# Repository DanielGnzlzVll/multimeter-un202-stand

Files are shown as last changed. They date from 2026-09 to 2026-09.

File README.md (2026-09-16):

# Unity UN202 multimeter stand

A compact folding kickstand for the Unity UN202 clamp multimeter, using
the existing top case screw (the one just below the jaw) as the mount
point. Three printed parts (pick one of the two base options) plus,
for the screw-based base, one M3 screw and nut:

- **`base_tab()`** — a small tab with a plain, fully-enclosed hole for
  a *replacement* screw (head ~5mm, shank ~3mm — swap in for the
  original case screw). The original screw comes out completely, is
  passed through this hole from behind, and driven back into the
  case, so its head clamps the tab flush. Because it's a plain hole
  (not a slot), the tab can only come off by being fully unscrewed
  again.
- **`base_plug()`** — a hardware-free alternative: a peg that presses
  tightly into the screw's recess (~5.6mm) instead of using the screw
  at all. Split into flexible fingers (a simple collet) so it
  self-adjusts across a range of real hole sizes instead of relying on
  one exact diameter. Simpler assembly, but it means pulling the screw
  out permanently and relying on the peg's grip alone.
- **`leg()`** — attaches to whichever base through a printed knuckle
  hinge, pinned with an M3 screw and nut. This is the part that
  actually folds flat against the meter when stowed and swings out to
  prop it up when deployed. **The M3 nut is the friction adjustment**
  — tighter clamps the knuckles together harder, holding the leg at
  whatever angle you leave it, including flush against the case.

Render/print with:

```
openscad --render -o stand.stl stand.scad
```

## File formats

- `stand.stl` — all three parts, laid out for printing (this is what
  you actually print).
- `stand.step` — the same layout, converted to STEP for tools that
  need it.
- `step/base_tab.step`, `step/base_plug.step`, `step/leg.step` — each
  part individually, for importing into a CAD assembly.

**Important caveat on the STEP files:** OpenSCAD has no true CAD
kernel — every curved surface (every cylinder, every hole) is always a
faceted polygon approximation (controlled by `$fn`), never a smooth
analytic surface. The STEP files here are that same faceted mesh
wrapped in STEP's container format (converted from the STL with
OpenCASCADE), not a real parametric/smooth-surface model. They're
useful for tools that only accept STEP, or for importing into a CAD
assembly, but don't expect smooth cylinders if you inspect the
surfaces closely, and don't expect to edit dimensions non-destructively
the way you could with a native CAD part — `stand.scad` is still the
actual source of truth for any dimensional changes.

## Renders

All three parts, laid out as they print:

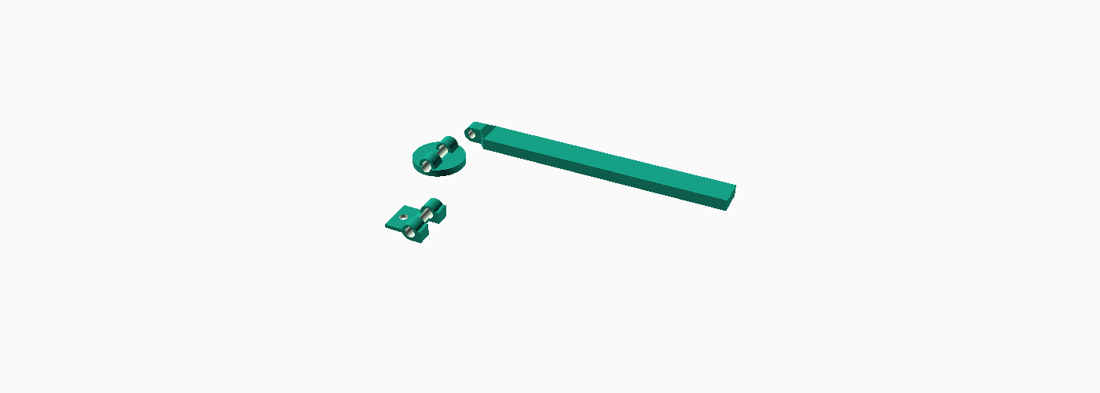
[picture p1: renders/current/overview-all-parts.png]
All parts


`base_tab` — thin insertion tab tapering into a thick hinge anchor:

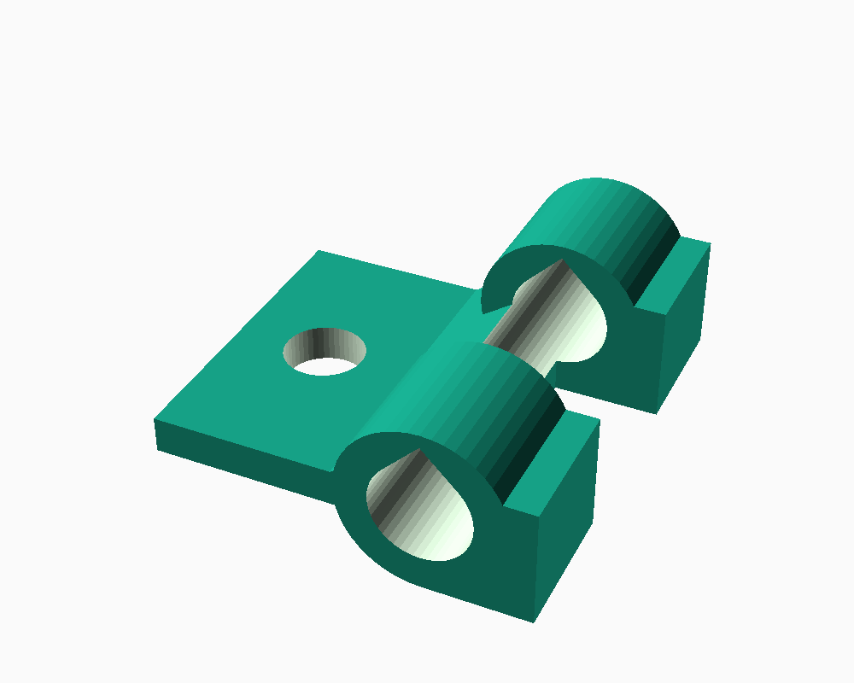
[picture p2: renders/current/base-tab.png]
base_tab


`base_plug` — press-fit peg, flange, and the same thick hinge anchor:

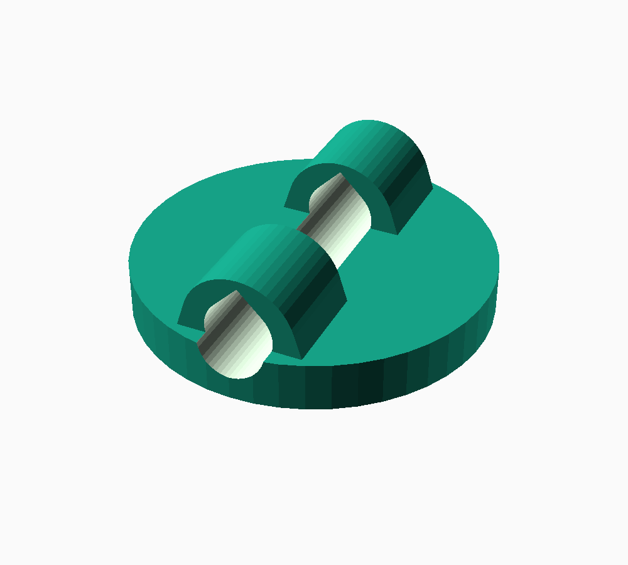
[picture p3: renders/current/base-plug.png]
base_plug


`leg` — hinge knuckle, tapered strip, foot pad:

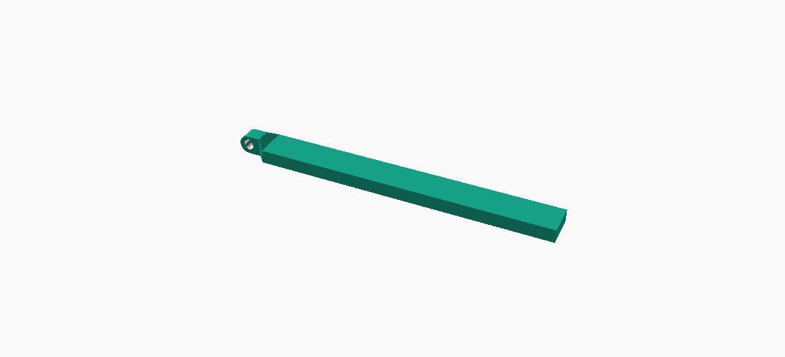
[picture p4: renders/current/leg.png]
leg


All parts are laid out flat side-by-side at the bottom of the file,
ready to print with no supports. Every M3 hinge bore uses a teardrop
profile (circle + a 45° point on top) instead of a plain round hole,
so it prints cleanly with no bridging/support even lying flat with the
bore axis horizontal. Each bore's cutter also extends well past the
finger/knuckle's own edges (not just ~1mm) — a smaller margin reliably
left a hair-thin sliver of uncut material right at the opening, close
enough to being a real M3 screw obstruction to fix outright. Verified
by literally modeling an M3 screw shaft and checking for zero overlap
with each part.

## Why two hinges' worth of thinking, but only one moving joint

The case screw's axis points straight into the case, so anything
pivoting directly on it can only sweep flat across the back (like a
clock hand) — it can't lift away from the surface to prop the meter
up. So the *base* (tab or plug) just anchors a fixed attachment point,
and a **separate** knuckle hinge (axis parallel to the case surface,
pinned by the M3 hardware) is what actually lets the leg fold out.
That second hinge is the only moving joint.

## Leg length math

With the meter resting on its bottom edge and tilted back to
`tilt_angle`, the top screw sits at height `screw_height_from_bottom *
sin(tilt_angle)` above the table. Swinging the leg out from
flush-against-the-case by `deploy_hinge_angle` needs a leg length of:

```
leg_length_raw = screw_height_from_bottom * sin(tilt_angle) / sin(tilt_angle - deploy_hinge_angle)
leg_length = leg_length_raw - leg_shorten
```

(`deploy_hinge_angle` must stay less than `tilt_angle`, or the leg
never reaches the table no matter how long it is.) All three inputs
are adjustable at the top of `stand.scad`. `leg_shorten` (25mm default)
trims the geometric result directly — in practice it came out longer
than the meter itself, and shortening it was simpler and more honest
than fudging `screw_height_from_bottom` (a measurement) or the angles
(deliberate choices) just to change the length.

## Before printing: verify these assumptions

- `screw_height_from_bottom` (115mm default): distance from the
  meter's bottom edge, along the back, up to the top screw. Estimated
  from product photos, not measured on your actual unit — **measure
  this**, it directly drives the leg length.
- `shank_d` (2.6mm default): diameter of the screw shank under the
  head. Only the head (5.1mm) and the recess it sits in (~5.6mm) were
  actually measured.
- `new_screw_head_d` (5mm) / `new_screw_shank_d` (3mm): the
  replacement screw's dimensions — both estimates, measure the actual
  screw you're using. `base_t` (1.6mm) no longer has to stay thinner
  than a loosened-screw gap now that the screw is fully removed for
  installation, but there's no reason to change it either. Past the
  screw hole, `base_tab` tapers up to a much thicker, wider anchor
  block (`base_thick_t` 5mm, `base_thick_w` 14mm) for the hinge
  fingers, the same reasoning as `base_plug`'s peg-to-flange taper.
- `base_w` (14mm default, up from 9mm): width of the zone the screw
  head clamps down on. Widened to match `base_thick_w` so the screw
  presses the tab against the case over a much bigger flat area
  instead of a strip barely wider than the head itself.
- `peg_len` (5.5mm default) and `peg_interference` (0.4mm default): how
  deep the screw's recess actually is, and how much oversized to print
  the peg for a tight press fit. `peg_len` is kept 0.5mm short of the
  full estimated recess depth so the peg doesn't bottom out/crash into
  whatever is at the base of that hole before the flange seats flush.
  Both are guesses — start with a test print of just `base_plug()`
  before committing to a full print. (Only matters for `base_plug`.)
- `base_plug`'s peg is split into `peg_slot_count` (3) flexible
  fingers by `peg_slots()` — a simple collet, so it self-adjusts to a
  slightly bigger or smaller real hole (compressing or springing out)
  instead of being one rigid diameter that's either loose or won't go
  in. `peg_solid_top` (1mm) keeps a solid, unsplit hub at the flange
  end for the fingers to cantilever from.
- `base_plug`'s flange (22mm diameter, 3mm thick) and gusseted fingers
  are sized to comfortably out-span the hinge fingers and give the
  leg's leverage a wide shoulder to load into — deliberately sturdier
  than the bare minimum, since this piece takes all the load with no
  screw backing it up.
- The hinge knuckle itself (`finger_w`, 6mm) is wider than the original
  design (4mm) since the leg's knuckle — the part actually cantilevering
  the leg's whole load — is only `finger_w - 0.4` wide, and 3.6mm was
  thin enough to be a real breakage risk.
- `base_tab` and `base_plug`'s two hinge fingers stay free-standing at
  the top -- deliberately. The gap above and between them is exactly
  where the leg's own strip has to sweep through as it pivots, so any
  fixed material bridging their tops (tried once, reverted) blocks the
  hinge from moving at all, even though it looks like harmless
  reinforcement in a static render.
- `base_tab`'s original taper only built up material on the near side
  (toward the tab) of each finger, leaving the far side of each
  cylinder completely unsupported. Fixed with a matching cap on that
  far side -- flat, at the same low Z as the rest of the anchor block
  (not stacked upward), and confined to each finger's own Y-width so
  it can't reach into the gap between them. Verified this doesn't
  introduce any new collision with the leg at any rotation angle
  (checked 0-180° in 15-30° steps): identical residual overlap with or
  without the cap, meaning what's left is a small pre-existing
  tolerance artifact from the tight ~0.2mm knuckle-to-gap clearance,
  not something this fix caused.
- `deploy_hinge_angle` (15° default): arbitrary choice balancing leg
  length against how far the leg has to swing out. Adjust and
  re-derive `leg_length` (automatic) if you want a shorter/longer leg.
- `base_gap_pad` (1.5mm) and `base_m3_hole_d` (4.2mm, up from the
  shared `m3_hole_d` 3.6mm): after printing the leg, its actual
  knuckle didn't leave a clear path for the M3 screw through both
  bases' finger holes — printed solid features commonly come out
  slightly oversized and holes slightly undersized, and a tight
  nominal fit and a tight nominal bore stack up fast. These two widen
  the bases' own finger gap and hinge bore only — `leg()`'s own
  dimensions (and the already-printed part) are completely untouched.
- `leg`'s foot pad matches the strip's own width/thickness (`foot_w` =
  `leg_w`, `foot_t` = `leg_t`) instead of being wider and thinner, so
  the whole leg is one constant rectangular cross-section end to end —
  it can be rotated 90° in the slicer (printed standing on edge for a
  different layer orientation) without a flared foot sticking out past
  the rotated profile.

## Assembly

**With `base_tab` (replacement screw):**
1. Remove the original case screw entirely.
2. Pass the replacement screw through `base_tab`'s hole from behind,
   then drive it into the case's original threaded hole. The bigger
   head clamps the tab flush against the case.

**With `base_plug` (no hardware, screw comes out):**
1. Remove the top case screw entirely.
2. Press `base_plug`'s peg firmly into the empty recess until the
   flange seats against the case. The split fingers should self-adjust
   to your actual hole size; sand the peg down a bit if it's still too
   tight to seat fully.

**Both:**
3. Sandwich `leg`'s knuckle between the base's two knuckles, push the
   M3 screw through, add the nut.
4. Tighten the nut until the leg holds its position under the meter's
   weight but you can still reposition it by hand.

## History

`renders/v1-rigid-prototype/` has renders of the very first design
iteration (a rigid, fixed-angle prop) that was replaced by the current
folding-hinge approach — kept for reference only.

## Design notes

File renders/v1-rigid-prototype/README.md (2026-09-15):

# v1 prototype (superseded)

Renders of the very first design iteration (git commit `e32ad1b`): a
single rigid piece that clipped onto the screw head via a keyhole slot
and held the meter at a fixed 60° angle via its own separate foot on
the table.

This was replaced by the current two-part folding hinge design because
it didn't match the actual goal: it stuck out further than wanted and
couldn't adjust its angle. Kept here for reference only — see the
top-level README for the current design.

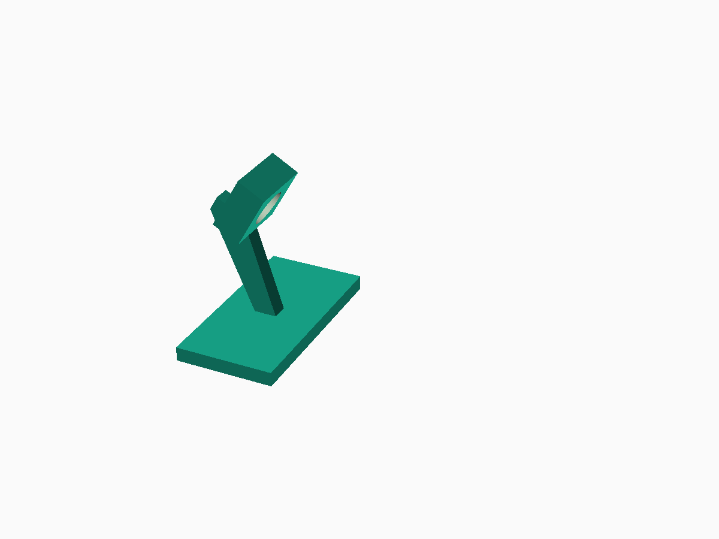
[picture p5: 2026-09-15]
renders/v1-rigid-prototype/overview.png

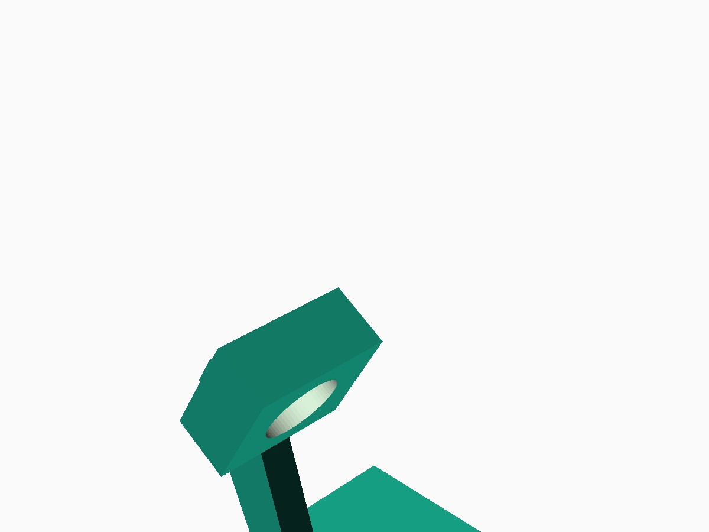
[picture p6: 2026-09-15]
renders/v1-rigid-prototype/clip-closeup.png

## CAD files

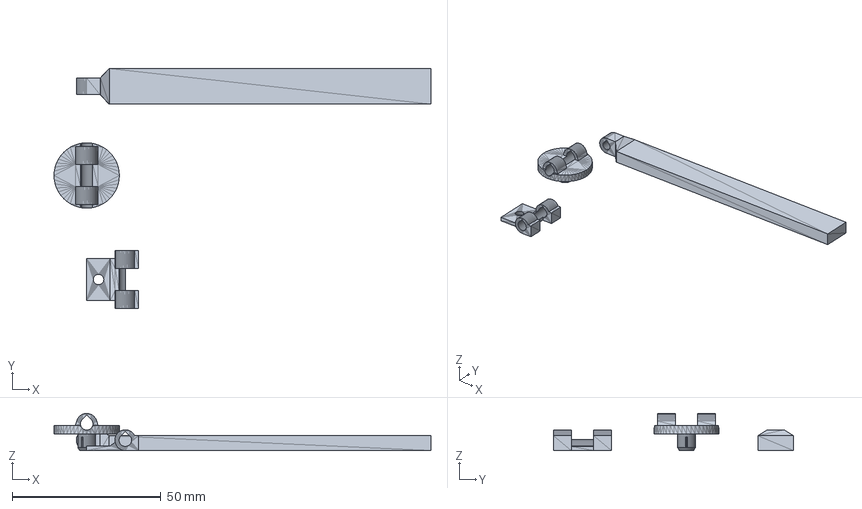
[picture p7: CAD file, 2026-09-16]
stand.step
126.8 x 80.8 x 12.5 mm

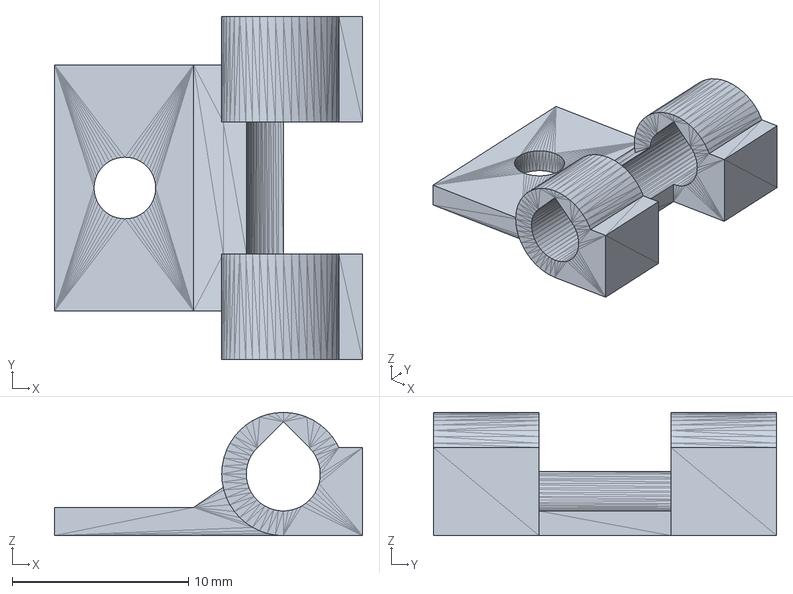
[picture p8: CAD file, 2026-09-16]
step/base_tab.step
17.5 x 19.5 x 7.00 mm

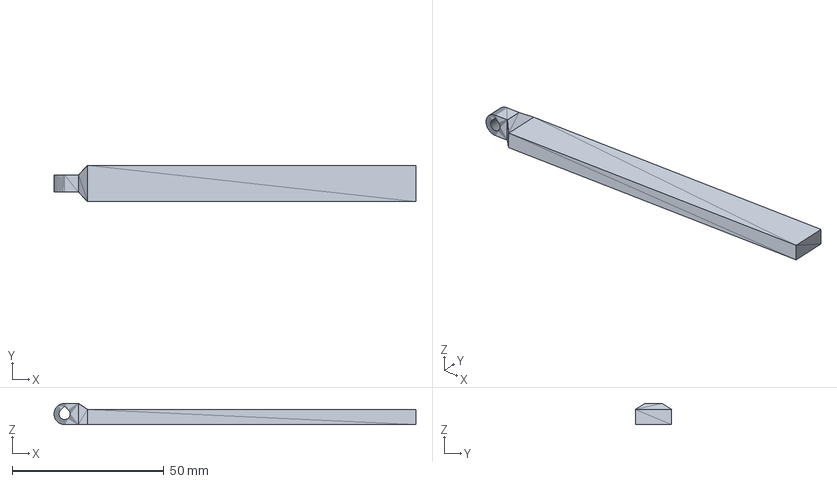
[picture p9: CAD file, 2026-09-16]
step/leg.step
119.3 x 12.0 x 7.00 mm

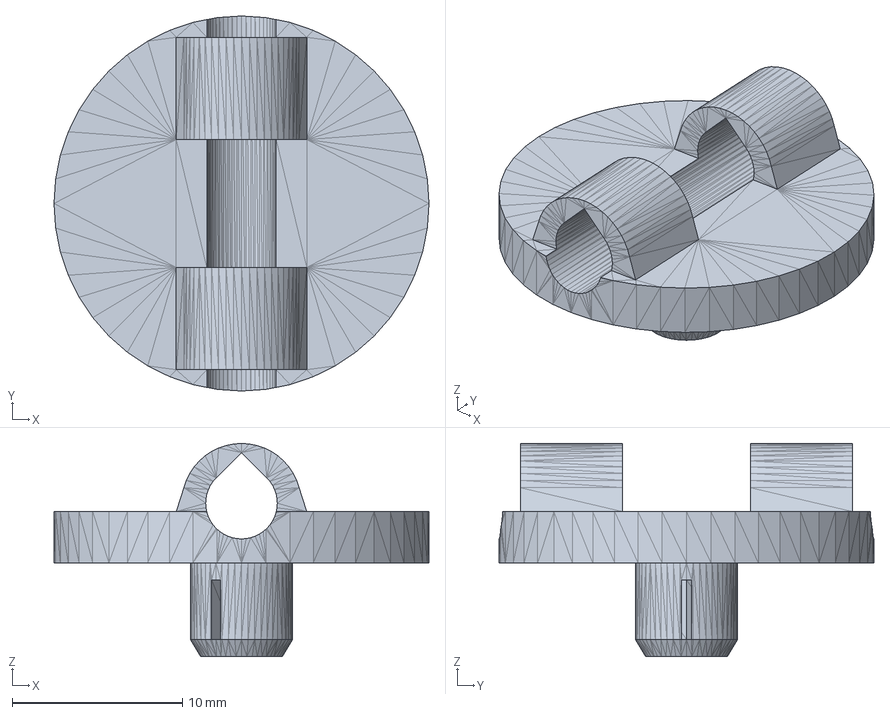
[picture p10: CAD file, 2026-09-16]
step/base_plug.step
22.0 x 22.0 x 12.5 mm

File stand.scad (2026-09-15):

// ============================================================
// Folding kickstand for Unity UN202 clamp multimeter
//
// One leg + a choice of two base attachments, plus one M3 screw
// and nut for the hinge:
//   1) base_tab()   - slides sideways under the loosened top case
//                     screw, sits flush against the case.
//   2) base_plug()  - alternative, no-hardware attachment: a peg
//                     that presses tightly into the screw's
//                     recess (no screw needed at all).
//   3) leg()        - attaches to whichever base through an M3
//                     bolt hinge (screw + nut = friction pivot).
//                     Folds flat against the case when stowed,
//                     swings out to prop the meter up when
//                     deployed. Tightening the nut sets how much
//                     friction holds whatever angle you leave it.
//
// MOST NUMBERS BELOW ARE ESTIMATES from product photos, not the
// real part. Print, test-fit, and correct the "ADJUST" sections.
// ============================================================

$fn = 48;

// ---------------- ADJUST: real screw/case measurements ----------
screw_head_d     = 5.1;   // measured
shank_d          = 2.6;   // ESTIMATE -- verify against the real screw shank
shank_clearance  = 0.5;
shank_hole_d     = shank_d + shank_clearance;
recess_d         = 5.6;   // measured diameter of the screw's recess/counterbore

// Distance from the meter's bottom edge, along the back, up to the
// TOP screw (below the jaw). Estimated from product photos --
// MEASURE THIS on the real meter, it directly sets the leg length.
screw_height_from_bottom = 115;

// ---------------- ADJUST: desired prop geometry ------------------
tilt_angle         = 60;  // meter's back angle from flat when propped up
deploy_hinge_angle = 15;  // how far the leg swings out (from lying flush
                           // against the case) to reach the table at
                           // tilt_angle. Must stay less than tilt_angle;
                           // smaller = longer leg but hugs the case
                           // closer while folding out.

// Required leg length so swinging the leg out by deploy_hinge_angle
// (from flush-against-the-case) lands the foot on the table with the
// meter resting on its bottom edge at tilt_angle. See README for the
// derivation.
leg_length_raw = screw_height_from_bottom * sin(tilt_angle) / sin(tilt_angle - deploy_hinge_angle);
// The geometric derivation above came out longer than the meter itself
// in practice. Trimmed directly rather than distorting the measured/
// chosen inputs above (which are either a real measurement or a
// deliberate angle choice, not free knobs to fudge for length alone).
leg_shorten = 25;
leg_length = leg_length_raw - leg_shorten;

// ---------------- Base tab (through-hole for a replacement screw) ---
// The original case screw is being swapped for a different one (head
// ~5mm, shank ~3mm) that's removed entirely, passed through a plain
// hole in the tab, and driven back into the case -- so the head
// clamps the tab flush against the case. This replaced an earlier
// loosen-and-slide keyhole design sized for the original screw; a
// plain hole is simpler now that the screw comes all the way out, and
// -- as a bonus -- means the tab can't come loose on its own at all,
// since it can only be removed by fully unscrewing it again.
new_screw_head_d       = 5;    // ADJUST -- replacement screw's head
new_screw_shank_d      = 3;    // ADJUST -- replacement screw's shank
new_screw_shank_clear  = 0.5;
new_screw_hole_d       = new_screw_shank_d + new_screw_shank_clear;

base_t = 1.6;  // thickness at the screw hole -- doesn't need to be
               // this thin anymore now that the screw is fully
               // removed for installation, but no reason to change it
base_l = 13;   // length, insertion edge to hinge knuckles
base_w = 14;   // width of the zone the screw head clamps down on --
               // widened from 9mm so it presses on a much bigger flat
               // area, instead of a narrow strip barely wider than
               // the head

// Past the screw hole, the tab doesn't need to stay thin -- nothing
// there has to slide under the screw head -- so it tapers up to a
// much thicker, wider anchor block for the hinge fingers to embed
// into, the same way base_plug()'s peg tapers into its flange.
base_thick_t = 5;   // thickness at the hinge end
base_thick_w = 14;  // width at the hinge end -- out-spans the fingers
                     // (hinge_span = 18mm) with real margin, instead of
                     // the original 9mm tab the fingers overhung badly

// ---------------- Press-fit base plug (no hardware) ---------------
// The peg alone (a rigid cylinder) was too loose -- printed hole sizes
// vary enough in practice that a single fixed diameter can't reliably
// grip. peg_interference is bumped up, and the peg itself is split
// into flexible fingers (see peg_slot_count etc. below) that compress
// or spring out to self-adjust across a range of real hole sizes,
// instead of relying on hitting one exact diameter.
peg_interference = 0.4;   // print the peg this much OVER recess_d;
                           // the split fingers below let it compress
                           // if that's too tight for your actual hole
peg_d    = recess_d + peg_interference;
peg_slot_count = 3;    // number of flexible fingers the peg is split
                        // into -- each can flex independently, so the
                        // peg self-adjusts to a slightly bigger or
                        // smaller real hole instead of being a single
                        // rigid diameter that's either loose or won't
                        // go in at all
peg_slot_w     = 0.6;  // slot width -- thin but printable at $fn=48
peg_solid_top  = 1;    // solid, unsplit hub left at the peg's own top
                        // (flange end) so the fingers have something
                        // rigid to cantilever from
peg_len  = 5.5;  // ADJUST -- how deep the recess actually is. Kept
                  // 0.5mm short of the full estimated recess depth so
                  // the peg doesn't bottom out/crash into whatever is
                  // at the base of that hole (e.g. the screw boss it
                  // used to thread into) before the flange seats flush.
                  // Shorten further if the real recess is shallower.
flange_d = 22;    // rests on the flat case surface around the recess.
                  // Sized to comfortably out-span the hinge fingers
                  // (hinge_span = 2*finger_w + knuckle_gap = 18mm) with
                  // real margin, so the leg's leverage has a wide
                  // shoulder to load into instead of overhanging it.
flange_t = 3;     // shoulder thickness -- doubled from 1.5mm so the
                  // flange resists the leg's leverage without flexing
                  // or cracking under load
lead_in  = 1;     // small chamfer at the peg's tip so it starts straight

// Gusset width: each hinge finger meets the flange through a hull()'d
// fillet instead of a bare, sharply-cornered tangent (same hull-taper
// trick leg() uses to blend its knuckle into the strip). Deliberately
// bigger than knuckle_od (7mm) -- anything narrower ends up entirely
// swallowed by the finger's own cylinder (hull of a shape inside
// another is a no-op), so it has to actually stick out past the
// finger to add material. The gusset's height is computed inside
// base_plug() itself, capped to stay clear of the hinge hole.
gusset_w = 9;   // x-extent of the gusset's flange-side footprint

// ---------------- Hinge (M3 screw + nut = friction pivot) --------
m3_hole_d     = 3.6;  // bumped from 3.4 -- FDM horizontal holes commonly print
                       // a bit undersized, and 3.4 was too tight for a clean M3 fit
knuckle_od    = 7;
knuckle_r     = knuckle_od / 2;
finger_w      = 6;                 // width of each base knuckle finger --
                                    // widened from 4mm since the leg's
                                    // knuckle (finger_w - 0.4) is the
                                    // thin part actually cantilevering
                                    // the whole leg's load
knuckle_gap   = finger_w;          // gap between the two base fingers
leg_knuckle_w = finger_w - 0.4;    // leg's single knuckle, fits the gap
hinge_span    = 2 * finger_w + knuckle_gap;
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

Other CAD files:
stand.stl

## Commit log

2026-09-15 Add parametric OpenSCAD kickstand for Unity UN202 multimeter
    Clips onto the existing case screw via a keyhole slot, meter's bottom
    edge rests on the table, fixed geometry caps the tilt at ~60 degrees.
    Several dimensions (screw shank, curve profile) are estimated and
    called out in the README for verification against the real part.
    [stand.scad, stand.stl]
2026-09-15 Redesign as a two-part folding hinge stand instead of a rigid kickstand
    The rigid fixed-angle prop didn't match what was wanted: something
    compact/flush against the case that folds and swings to any angle via
    friction. Replaced with a small base tab that clips under the real top
    case screw (per an actual back-panel photo) plus a leg on a separate
    M3 screw+nut knuckle hinge, since the case screw's own axis can only
    sweep flat across the back and can't provide the fold-out motion.
    [stand.scad, stand.stl]
2026-09-15 Add reference renders of the original v1 rigid-prop prototype
    Kept for history alongside the current folding-hinge design.
2026-09-15 Widen leg, ease hinge-bore printing, add hardware-free press-fit base
    - Leg is wider overall and the section right at the hinge knuckle is
    now blended in with a smooth taper instead of stepping straight into
    a much narrower strip, so it isn't pinched and prints more cleanly.
    - Every M3 hinge bore now uses a teardrop profile instead of a plain
    circle, so it prints without bridging/support even lying flat with
    the bore axis horizontal.
    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
    [stand.scad, stand.stl]
2026-09-15 Increase M3 hinge hole to 3.6mm for reliable clearance after printing
    [stand.scad, stand.stl]
2026-09-15 Fix leg() strip/foot floating above bed in print orientation
    The strip and foot pad cross-sections were vertically centered on the
    knuckle's rotation axis (Z = knuckle_r), while the knuckle cylinder
    itself spans Z=0 to Z=knuckle_od (tangent to the bed at Z=0). This left
    almost the entire ~140mm leg hovering above the bed except for a
    razor-thin tangent line under the knuckle when printed flat.
    Move the strip and foot pad cubes to start at Z=0 so their bottom face
    is flush with the knuckle's own bottom, matching the convention already
    used by base_tab()/base_plug(). Only the Z-translate of the two hull()
    strip cross-sections and the foot pad cube changed; the knuckle geometry,
    hole position,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
    [stand.scad]
2026-09-15 Fix hinge hole nearly closed by the leg's knuckle-to-strip taper
    The smooth taper hull'd the knuckle directly against the full-width
    strip cross-section, which flared out right over the hole's open ends
    and left only a thin sliver actually exposed. Split it into two hull
    stages: the first keeps the knuckle's own width all the way past the
    hole, the second (safely beyond it) does the actual widening/thinning
    down to the strip's cross-section.
    [stand.scad, stand.stl]
2026-09-15 Reinforce base_plug() against snapping under leg leverage
    The press-fit peg's flange was only 9mm diameter, barely bigger than
    the 7mm knuckle_od, so the hinge fingers (spanning 12mm together)
    actually overhung the shoulder they were supposed to be anchored to.
    Combined with a 1.5mm flange and a bare tangent-line join between
    each finger and the flange, the whole finger/flange junction was a
    likely snap point under the leg's leverage.
    - flange_d: 9mm -> 16mm, so the shoulder actually underlaps both
    fingers with margin instead of leaving them cantilevered past its
    edge, and gives real shoulder area to spread load into.
    - flange_t: 1.5mm -> 3mm, so the shoulder resists leverage without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
    [stand.scad]
2026-09-15 Update README for base_plug robustness changes
    [stand.stl]
2026-09-15 Fix real hinge-hole obstruction and widen the leg's load-bearing knuckle
    Root cause of the "screw can't go through it" report: the hole cutter's
    margin past each finger/knuckle's Y edge was only ~1mm, which reliably
    left a hair-thin sliver of uncut material right at the opening -- not
    a rendering artifact. Confirmed by modeling an actual M3 screw shaft
    and intersecting it with each part; margin increased substantially,
    re-verified as fully clear (zero overlap) on base_tab, base_plug, and
    leg.
    Also restored base_plug's reinforcing gusset (removed last commit on
    a mistaken theory that it caused the blockage -- it didn't, and
    removing it was a pure regression), keeping its height capped below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
    [stand.scad, stand.stl]
2026-09-15 Robustify base_tab the same way base_plug was: thin insertion, thick hinge anchor
    The tab had to stay thin (1.6mm) everywhere to slide under the loosened
    screw head, but that meant the hinge fingers only embedded into 1.6mm
    of material -- even thinner than base_plug's original 1.5mm flange.
    Only the zone actually sliding under the screw head needs to stay thin;
    past the screw hole it now tapers up to a much thicker (5mm), wider
    (14mm, out-spanning the fingers) anchor block, mirroring base_plug's
    peg-to-flange approach.
    Re-verified with the same screw-shaft collision test used for the
    other two parts: zero overlap on all three.
    [stand.scad, stand.stl]
2026-09-15 Add hinge bridges, trim peg depth for clearance, add current renders
    - hinge_bridge(): both base_tab and base_plug had their two hinge
    fingers connected only at the bottom (through the tab/flange), left
    as bare unconnected pins at the top -- all the leg's leverage had to
    be resisted by each finger cantilevering alone. Spans across the
    tops to close them into a single rigid loop, staying lifted clear of
    the leg's own knuckle in the gap (verified: zero collision between
    the bridge and the leg's knuckle).
    - peg_len trimmed 6mm -> 5.5mm so base_plug's peg doesn't bottom out
    against whatever is at the base of the recess before the flange
    seats flush.
    - Added renders/current/ with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
    [stand.scad, stand.stl]
2026-09-15 Revert hinge bridge -- it blocked the leg's rotation entirely
    The bridge connecting the tops of the two hinge fingers sat directly
    in the leg's swept rotation path (it pivots about the Y axis through
    the knuckle, sweeping through the X-Z plane) -- fixed material there
    blocks the hinge from moving at all, regardless of how it looked in a
    static render or that it passed manifold/collision checks (those don't
    model motion). Removed hinge_bridge() entirely and its two call sites;
    back to the fingers being free-standing above the tab/flange, which is
    correct since that space is exactly where the leg needs to swing.
    Also adds CLAUDE.md encoding the process rule going forward: render
    and visually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
    [stand.scad, stand.stl]
2026-09-15 Support the far side of base_tab's hinge fingers with in-plane material
    Correctly addresses the original request: base_tab's taper only built
    up material on the near side (toward the tab) of each finger, ending
    exactly at the finger's own center -- the far half of each cylinder was
    left completely unsupported, floating with nothing behind it. Added a
    matching cap on that far side, flat at the same low Z as the rest of
    the anchor block (not stacked upward along Z, which is what the
    reverted "hinge bridge" got wrong) and confined to each finger's own
    Y-width so it can't reach into the gap the leg's knuckle needs.
    Verified with the swept-rotation check from CLAUDE.md: intersected the
    leg again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
    [stand.scad, stand.stl]
2026-09-15 Shorten leg by 25mm, widen base_tab's screw-clamping pad
    - leg_shorten (25mm) trims leg_length_raw directly -- the geometric
    derivation came out longer than the meter itself in practice.
    Trimming the result was more honest than fudging the measured/
    chosen inputs (screw_height_from_bottom, the angles) just to hit a
    target length.
    - base_w widened 9mm -> 14mm (matching base_thick_w) so the screw head
    clamps the tab against the case over a much bigger flat area, not a
    strip barely wider than the head itself.
    Rendered and reviewed both changes before committing (iso + top-down
    views) per CLAUDE.md.
    [stand.scad, stand.stl]
2026-09-15 Close base_tab's keyhole slot, make leg's foot pad match strip dims
    - base_tab: replaced the open-sided slot with a closed keyhole (head-
    clearance entry hole, fully enclosed by material, connected by a
    channel to the shank's resting hole). The old slot was open to the
    tab's edge, so the tab could slide back out on its own if the screw
    loosened, from vibration, or gravity. Now it can only come off by
    deliberately realigning it back over the entry hole. base_l grew
    11mm -> 14mm to fit the longer slot.
    - leg: foot pad's footprint now matches the strip exactly (18x3 ->
    12x5, same as leg_w/leg_t) instead of being wider and thinner, so
    the whole leg is a single constant rectangula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
    [stand.scad, stand.stl]
2026-09-15 Fix printed-leg fit, plain through-hole for a new screw, self-adjusting peg
    base_tab and base_plug only -- leg() is untouched and byte-for-byte
    identical (verified: same facet count as before), since it's already
    printed and won't be reprinted.
    - Widened the bases' own hinge finger gap (base_gap_pad) and bore
    diameter (base_m3_hole_d, 4.2mm vs the shared 3.6mm) so the M3 screw
    has a clear path through both bases and the already-printed leg's
    knuckle. The printed leg didn't leave enough room: solid features
    print slightly big, holes print slightly small, and a tight nominal
    fit/bore stack those errors together into no usable clearance.
    - base_tab: replaced the closed keyhole with a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
    [stand.scad, stand.stl]
2026-09-16 Add STEP exports alongside the STL
    - stand.step: same print-layout geometry as stand.stl, converted with
    OpenCASCADE (OCP) since the installed OpenSCAD (2021.01) has no
    native STEP export.
    - step/base_tab.step, step/base_plug.step, step/leg.step: each part
    individually, for importing into a CAD assembly.
    These are faceted meshes wrapped in STEP's container format, not a
    true smooth/parametric model -- OpenSCAD has no CAD kernel, so this is
    inherent to anything exported from it. Noted clearly in the README so
    it's not mistaken for more than it is. stand.scad remains the actual
    source of truth for dimensions.
    [base_plug.step, base_tab.step, leg.step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]
